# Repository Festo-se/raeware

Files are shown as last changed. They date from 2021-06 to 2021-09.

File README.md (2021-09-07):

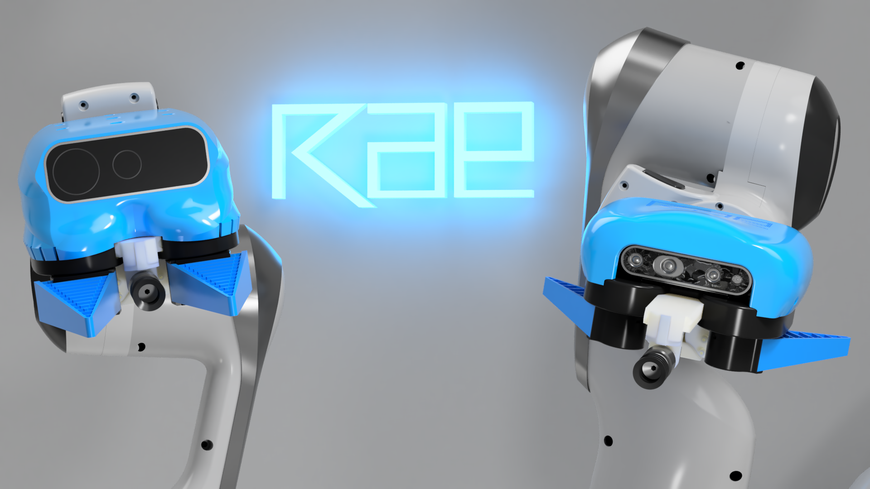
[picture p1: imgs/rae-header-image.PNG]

>[>> Fusion 360 - WebViewer](https://a360.co/2W6mHcp)

## About the Rae Project
Rae stays for *Robot-autonomy-
effector* and is an __OpenSource__ based modular end-of-arm tool with integrated __eye-in-hand__ depth camera which enables researchers, AI-enthusiasts and engineers to develop and deploy autonomous applications for robot manipulators. The 6 different module-types helps to solve various modern challenges in Robotics as for example bin-picking, packaging or tool-based automation. The design originates from the Bachelor-thesis created by Roman Baur in cooporation with Festo SE & Co. KG and the University of applied Sciences in Esslingen.

## [Table of content](#table-of-content)

- [Getting Started](#getting-started)
- [Base-System](#base-system)
- [Realsense System](#realsense-system)
- [Kinect System](#kinect-system)
- [Gripper Fingers](#gripper-fingers)
  - [Festo DAHS-80 Radialgripper](#festo-dahs-80-radialgripper)
  - [Festo DAHS-120 Radialgripper](#festo-dahs-120-radialgripper)
- [Flanges](#flanges)
- [Vacuum Module](#vacuum-module)
  - [double-pump](#double-pump)
  - [big-pump](#big-pump)
- [Suction modules](#suction-modules)
  - [Angular compensation](#angular-compensation)
  - [Linear compensation](#linear-compensation)
- [Electrical Circuit](#electrical-circuit)
- [Cable-set](#cable-set)
- [Credits](#credits)
  - [Bachelors thesis and extension by Roman Baur:](#bachelors-thesis-and-extension-by-roman-baur)
  - [Supervisors Festo SE & Co. KG:](#supervisors-festo-se--co-kg)
  - [Supervisors HS Esslingen:](#supervisors-hs-esslingen)
    - [Bachelors Thesis RAE v 1.0:](#bachelors-thesis-rae-v-10)
    - [RAE v 2.0:](#rae-v-20)

# Getting Started

How I get an working rae:

1. Download the .stl files from the [base-system](base-system) including drive and guide parts
2. Choose whether you want a [realsense](perception-modules/realsense) or a [kinect](perception-modules/kinect) perception system and download the according .stl files.
3. Print it with a high-quality SLS-Printer.
4. Assemble the the printed parts and the electric components with the appropriate screws.
5. Download the Image for the embedded linux called raeos and flash it on an SD-Card. Then boot the system.

> If you want to have an assembled and preinstalled rae, please contact [themakeservice](#)

How to set up my rae:
1. Install the raeros-client on your host system and setup an ethernet or wireless based connection to the rae-system.

# Base-System
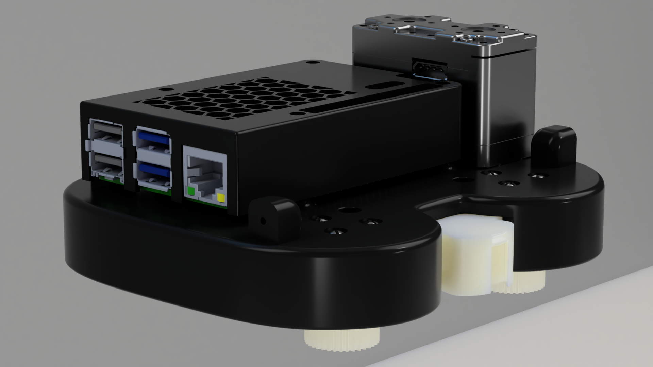
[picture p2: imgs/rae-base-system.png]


> [>> base-system](base-system)

# Realsense System

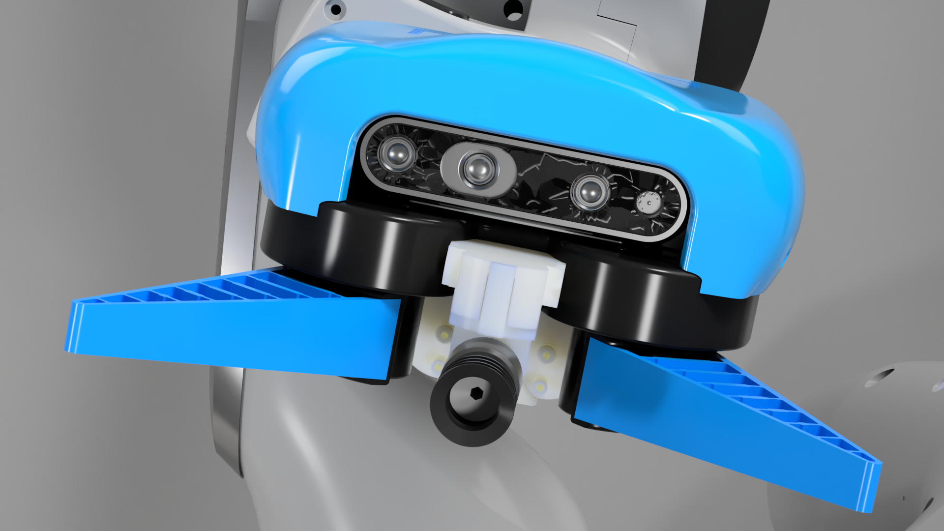
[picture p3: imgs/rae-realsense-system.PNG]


> [>> realsense-system](perception-modules/realsense)

# Kinect System
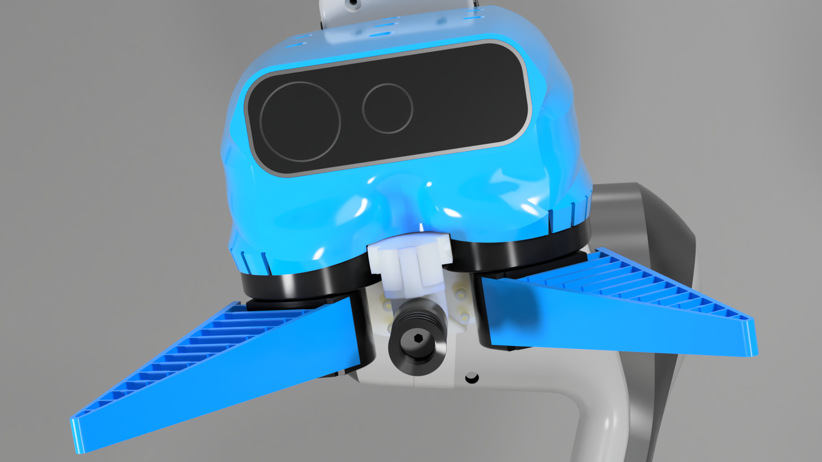
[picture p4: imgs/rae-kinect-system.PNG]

> [>> kinect-system](perception-modules/kinect)

# Gripper Fingers
## Festo DAHS-80 Radialgripper
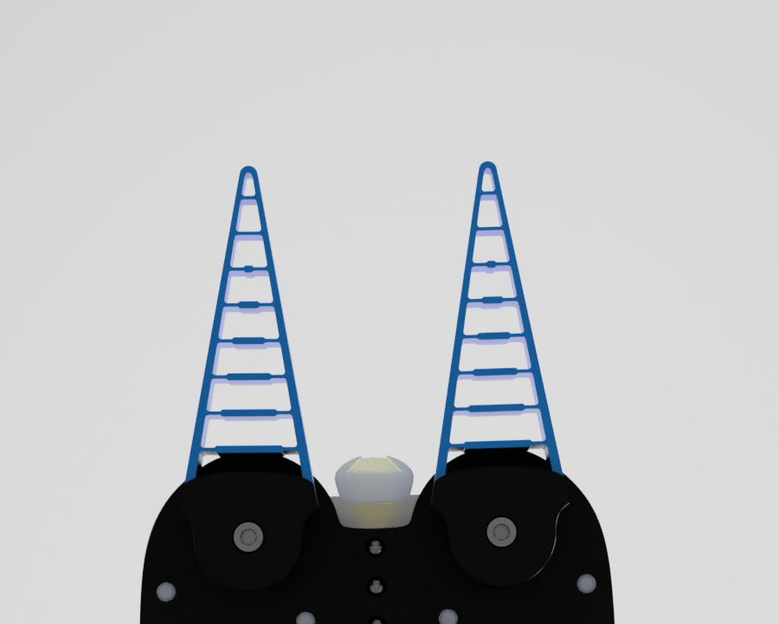
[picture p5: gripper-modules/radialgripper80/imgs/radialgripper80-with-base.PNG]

> [>> radialgripper80](gripper-modules/radialgripper80)
> 
## Festo DAHS-120 Radialgripper
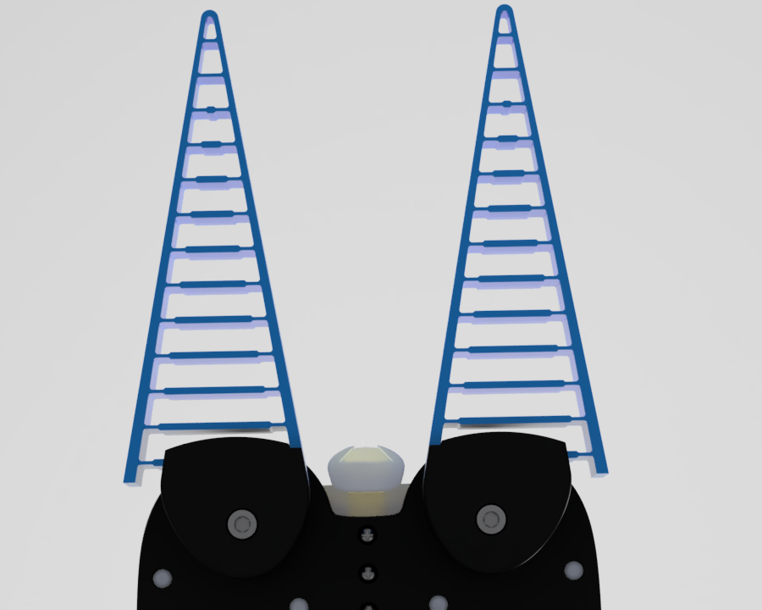
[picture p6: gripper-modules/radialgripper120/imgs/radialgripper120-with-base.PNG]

> [>> radialgripper120](gripper-modules/radialgripper120)
# Flanges
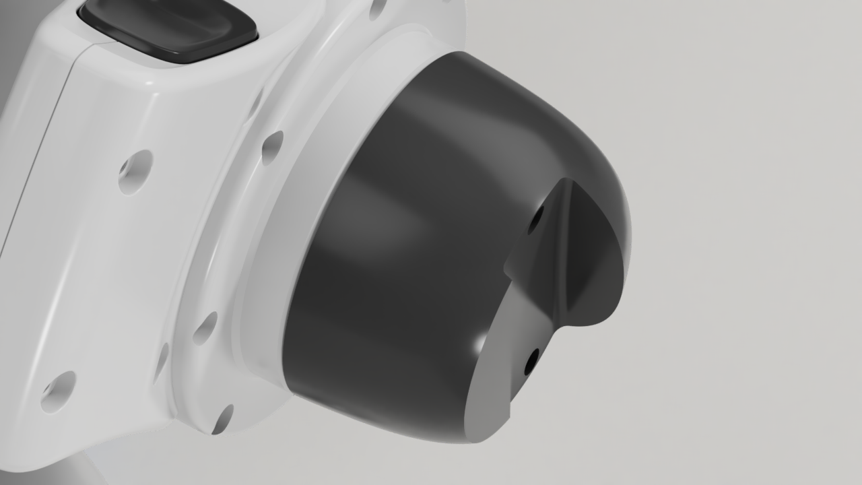
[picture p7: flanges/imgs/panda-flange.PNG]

> [>> Franka-Panda-Flange](flanges)

# Vacuum Module
## double-pump
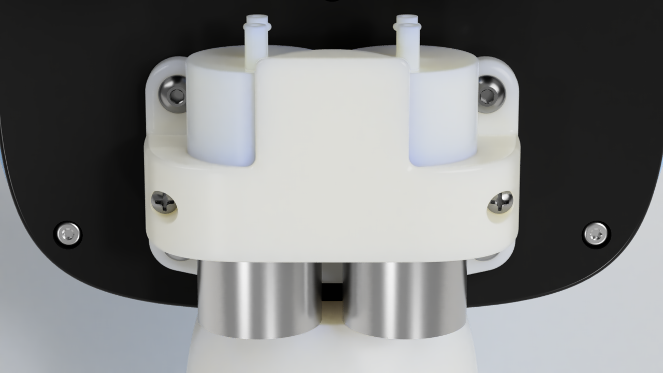
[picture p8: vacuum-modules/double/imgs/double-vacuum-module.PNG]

> [>> double-vacuum-module](vacuum-modules/double)

## big-pump
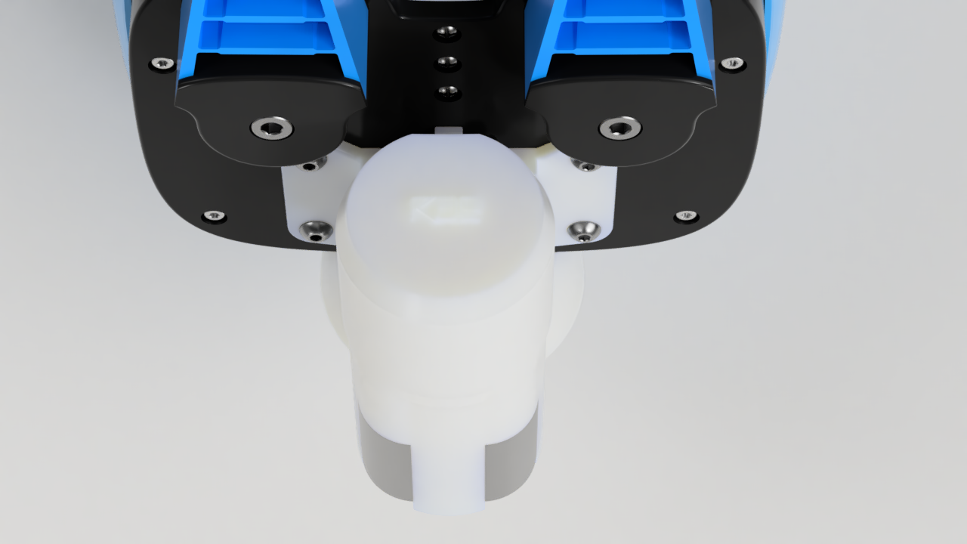
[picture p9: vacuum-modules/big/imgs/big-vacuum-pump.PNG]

> [>> big-vacuum-module](vacuum-modules/big)

# Suction modules
## Angular compensation
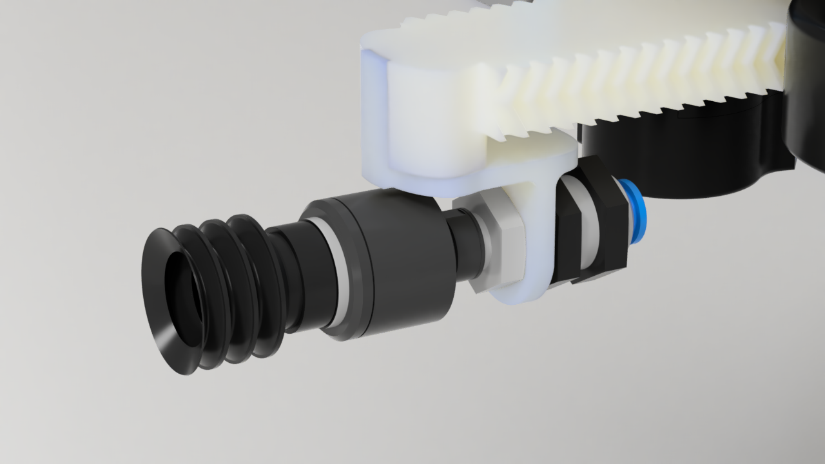
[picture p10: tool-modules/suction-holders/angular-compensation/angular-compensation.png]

> [>> angular-compensation-module](tool-modules/suction-holders/angular-compensation)
> 
## Linear compensation
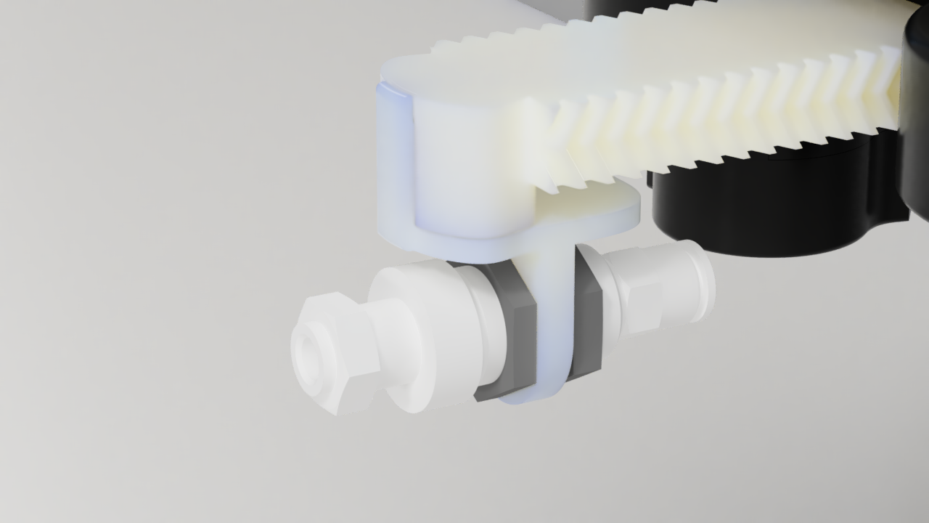
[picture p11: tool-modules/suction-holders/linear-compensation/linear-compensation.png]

> [>> linear-compensation-module](tool-modules/suction-holders/linear-compensation)

# Electrical Circuit
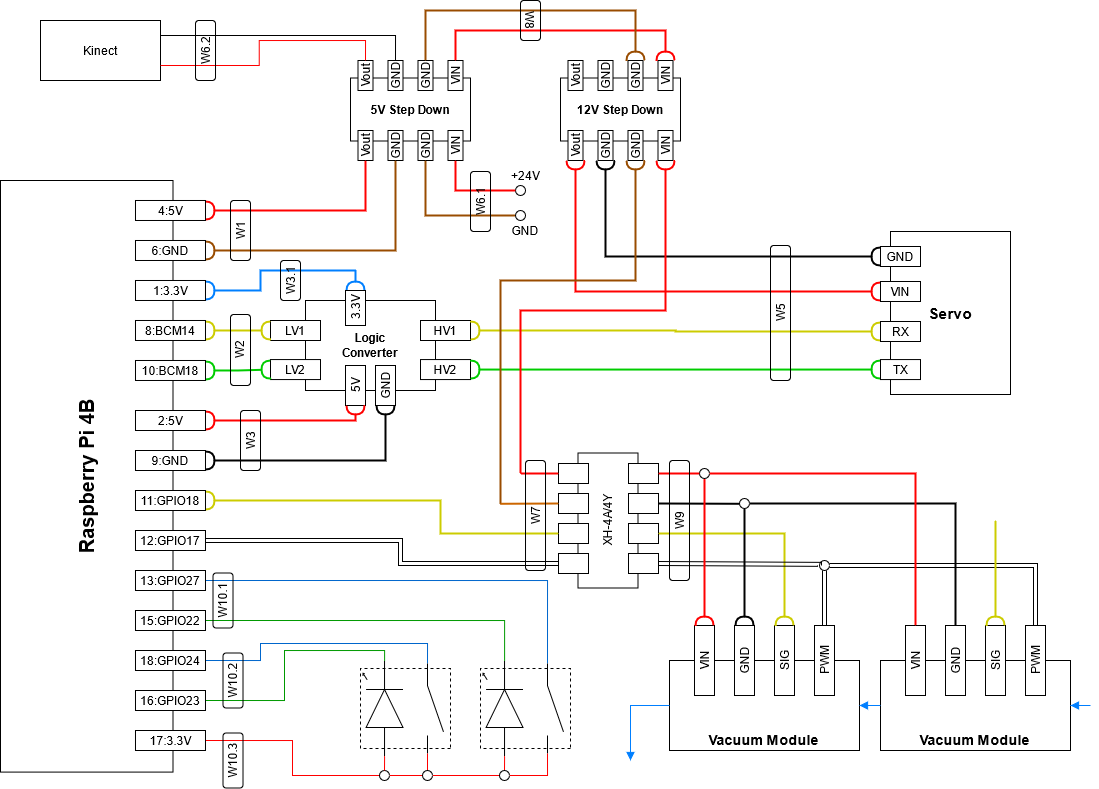
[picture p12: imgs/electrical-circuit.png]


# Cable-set
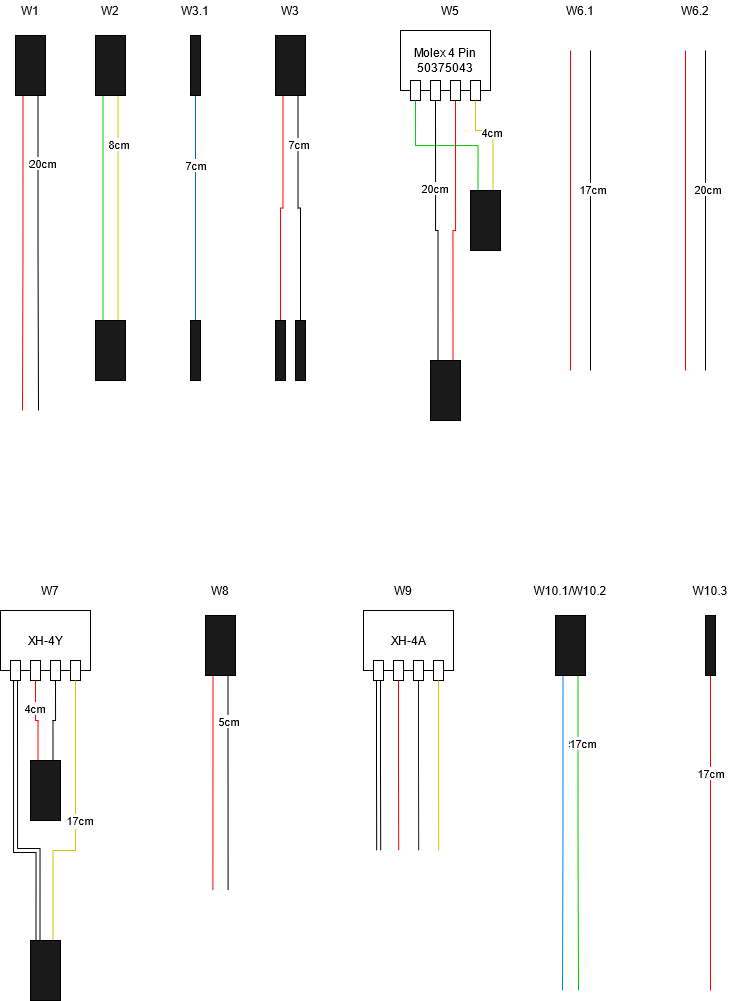
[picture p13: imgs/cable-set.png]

# Credits

## Bachelors thesis and extension by Roman Baur:
* Modular Concept
* Mechanical-, Electrical- and Software-Design

## Supervisors Festo SE & Co. KG:

Daniel Brauchle, Dionysios Satikidis, Timo Schwarzer

## Supervisors HS Esslingen:

### Bachelors Thesis RAE v 1.0:
Prof. Clemens Klöck, Dionysios Satikidis

### RAE v 2.0:
Prof. Thao Dang

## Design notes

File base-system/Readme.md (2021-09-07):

# Dynamixel Base System
>Coming soon
# Lynxmotion Base System
## Assembly animation
Base System assembly (https://www.youtube.com/watch?v=B7FRX5-CgM0 "Base System assembly")

## Partlists
### Electronic
| Name  | Description  | Reference |
|---|---|---|
| Raspberry Pi 4B  | Embedded Linux Computer | [raspberrypi.org](https://www.raspberrypi.org/products/raspberry-pi-4-model-b/)
|Lynxmotion LSS HT1 | Smart Servomotor | [robotshop.com](https://www.robotshop.com/de/de/lynxmotion-smart-servo-lss---hohes-drehmoment-ht1.html)
| Pololu D36V50F12 | Step Down 24V/12V |  [pololu](https://www.pololu.com/product/4095) |
| Pololu D36V50F5 | Step Down 24V/5V | [pololu](https://www.pololu.com/product/4091) |

### Screws
| Name | Application |Qty | Reference |
| --- |--- | --- | --- |
| 3.0X14 TORX rounded head | Case-screws | 6 | [Wuerth](https://eshop.wuerth.de/WUPLAST-Linsenkopfschraube-mit-Innensechsrund-SHR-LIKPF-W1452-T10-109-A3K-3X14/42283%20%2014.sku/de/DE/EUR/) |
| 3.0X6 TORX rounded head | Trapezodial-guide | 3 | [Wuerth](https://eshop.wuerth.de/WUPLAST-Linsenkopfschraube-mit-Innensechsrund-SHR-LIKPF-W1452-T10-109-A3K-3X6/42283%20%206.sku/de/DE/EUR/)|
| 3.0X10 TORX rounded head| Shafts| 6 | [Wuerth](https://eshop.wuerth.de/WUPLAST-Linsenkopfschraube-mit-Innensechsrund-SHR-LIKPF-W1452-T10-109-A3K-3X10/42283%20%2010.sku/de/DE/EUR/) |
| 2-56, 1/4"  SOCKET HEAD | Servomotor | 6 | [McMaster](https://www.mcmaster.com/91251A077/) |
| M5 Square-Nut DIN 557 | Flanges | 2 | [Wuerth](https://eshop.wuerth.de/Produktkategorien/DIN-557-Stahl-5-verzinkt/14013512180106.cyid/1401.cgid/de/DE/EUR/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) |

# Drive Parts
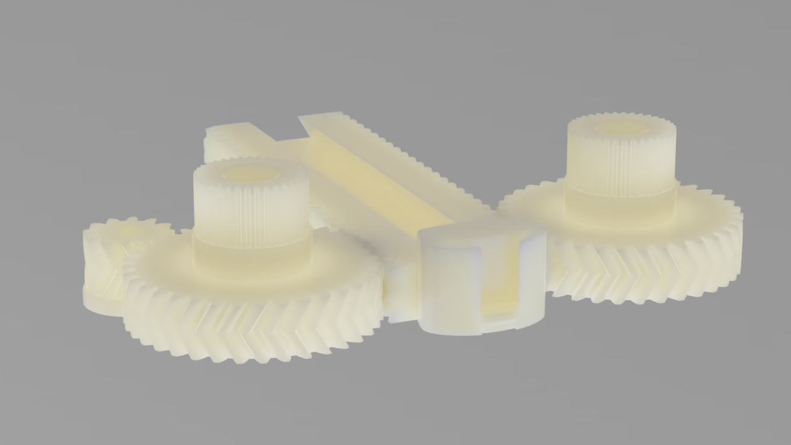
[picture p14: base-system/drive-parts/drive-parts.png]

> [>> drive-parts](drive-parts)

# Metal Guide Parts
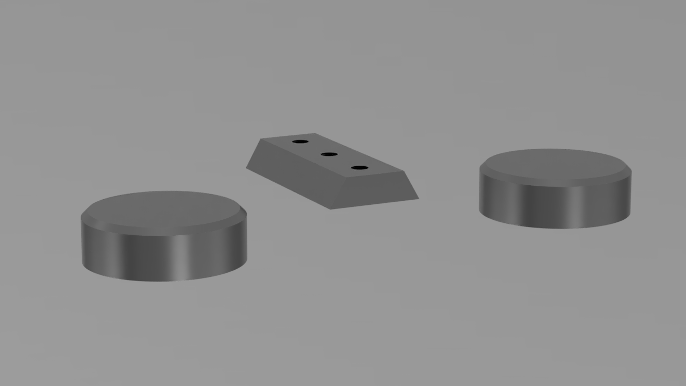
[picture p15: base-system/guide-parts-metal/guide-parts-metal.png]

> [>> metal-guide-parts](guide-parts-metal)

# Nylon Guide Parts
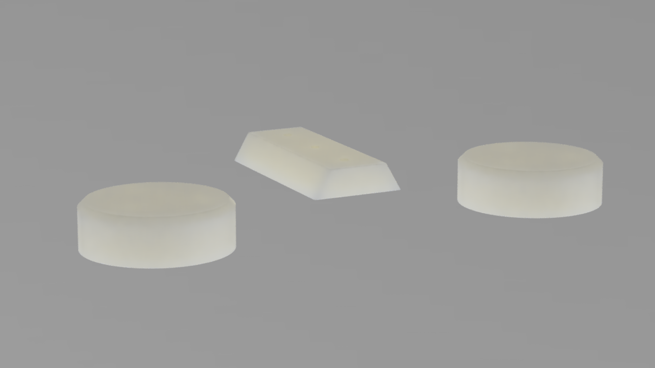
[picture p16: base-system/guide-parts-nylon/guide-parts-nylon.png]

> [>> metal-guide-nylon](guide-parts-nylon)

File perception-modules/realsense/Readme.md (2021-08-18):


Depth Kamera D435i | [specs](https://www.intel.de/content/www/de/de/products/sku/190004/intel-realsense-depth-camera-d435i/specifications.html)

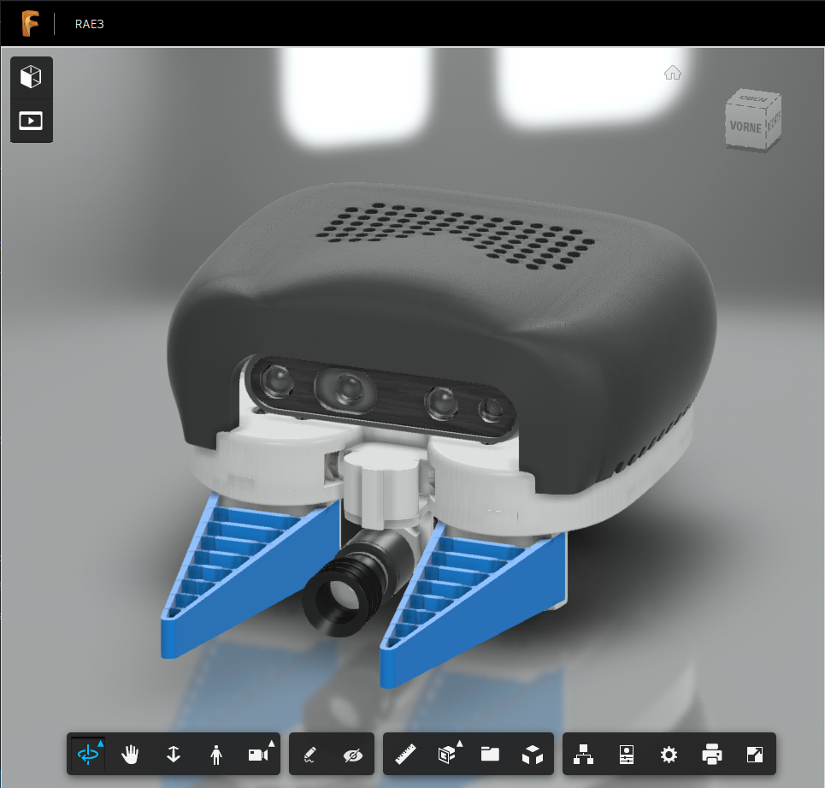
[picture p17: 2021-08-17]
imgs/fusion360-webviewer.PNG

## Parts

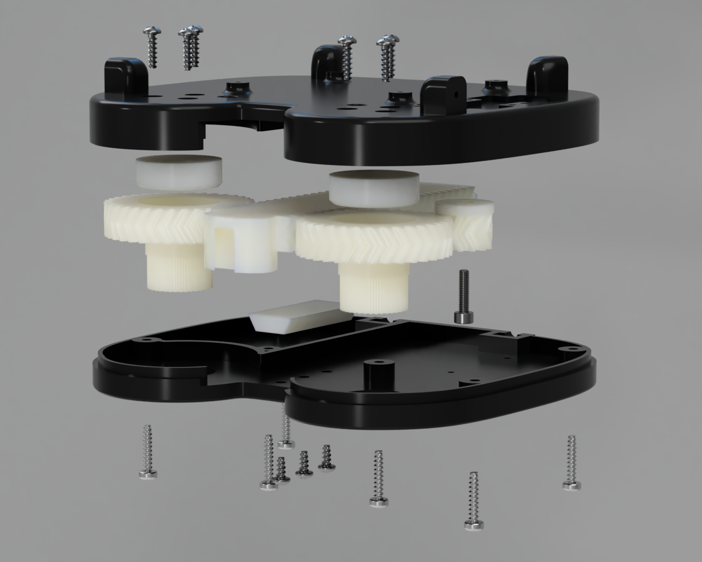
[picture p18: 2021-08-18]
base-system/lynxmotion-system/imgs/exploded-view-mechanical-parts.PNG

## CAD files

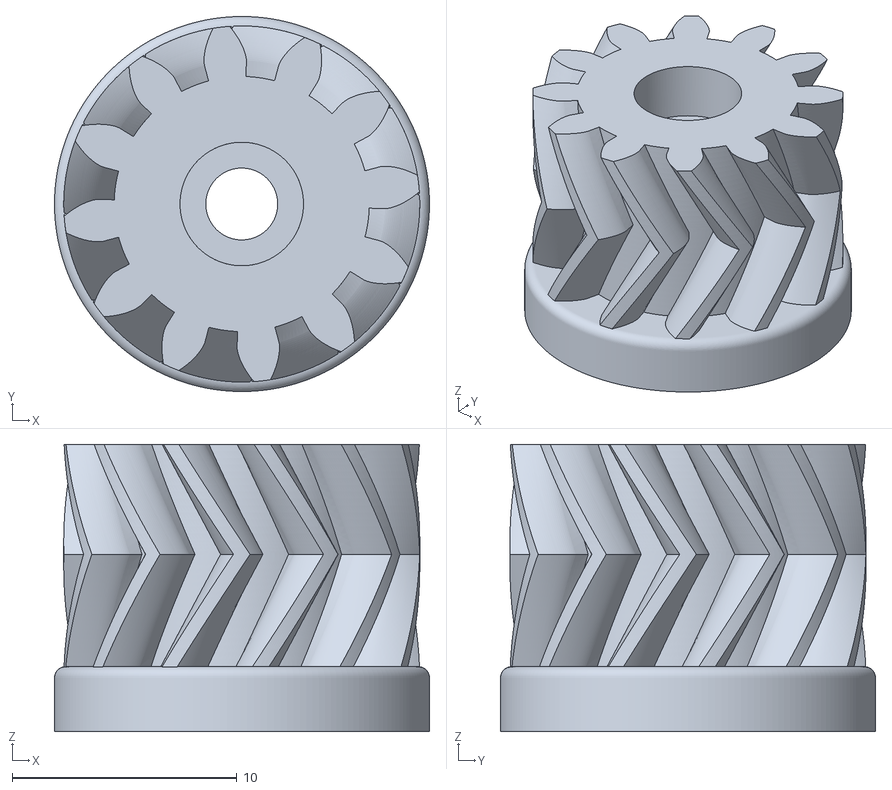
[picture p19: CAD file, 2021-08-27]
base-system/drive-parts/horn.stl
16.7 x 16.7 x 12.8

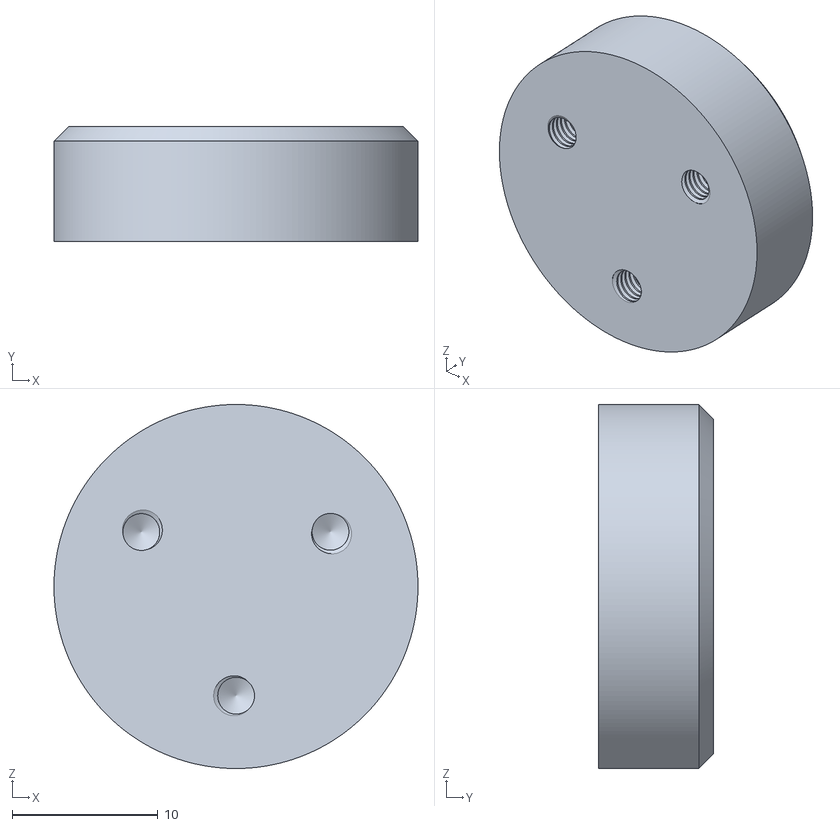
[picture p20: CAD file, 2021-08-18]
base-system/guide-parts-metal/right-shaft.stl
25.0 x 7.90 x 25.0

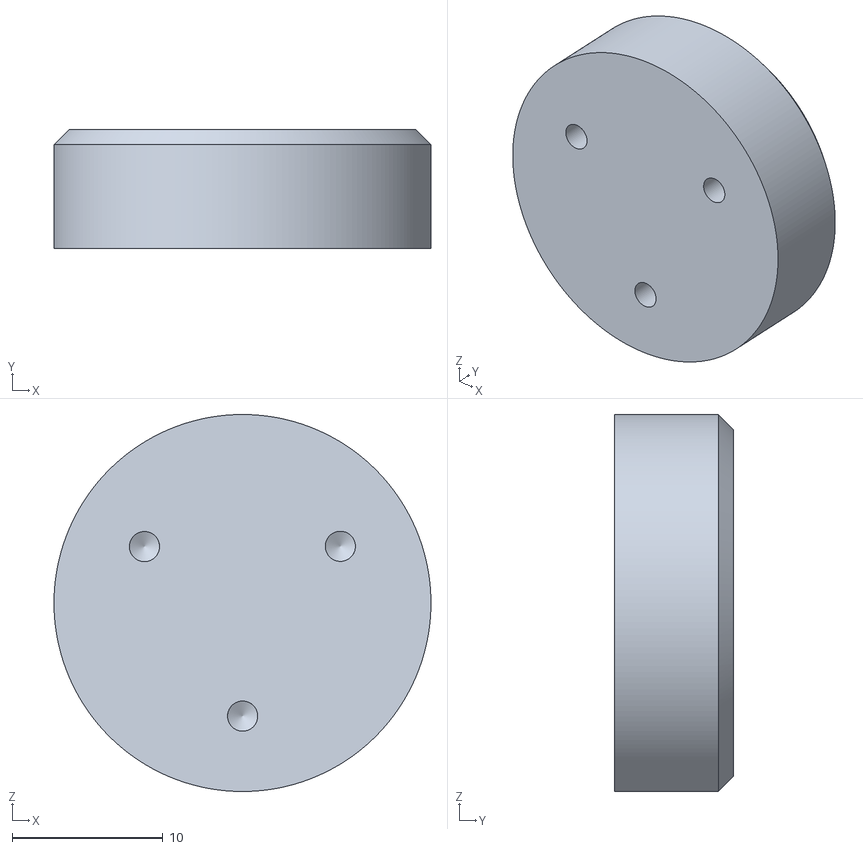
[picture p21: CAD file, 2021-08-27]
base-system/guide-parts-nylon/left-shaft.stl
25.0 x 7.90 x 25.0

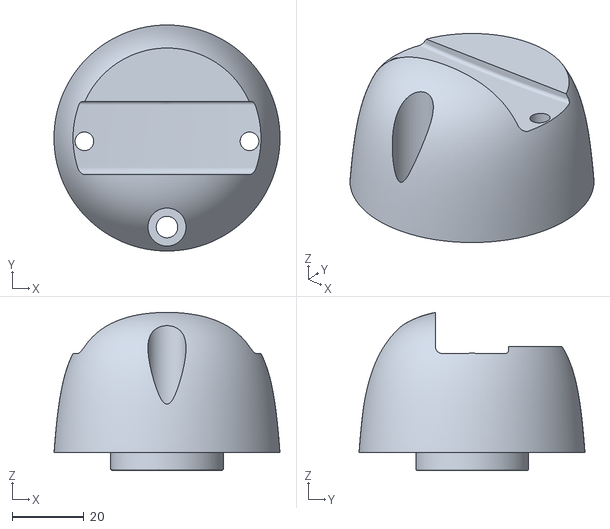
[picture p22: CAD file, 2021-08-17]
flanges/panda-flange.stl
63.0 x 63.0 x 44.1

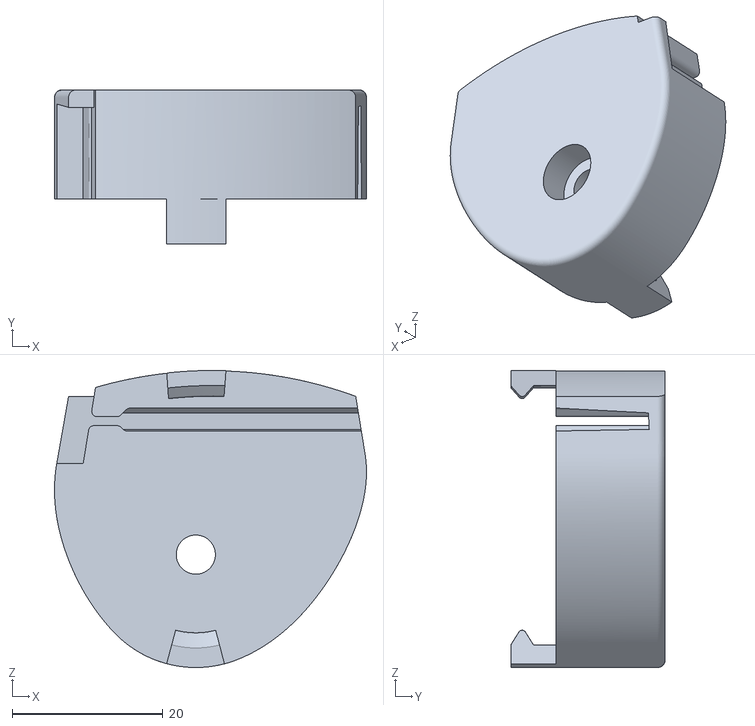
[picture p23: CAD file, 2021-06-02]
gripper-modules/radialgripper120/left_top.stl
41.5 x 20.5 x 39.5

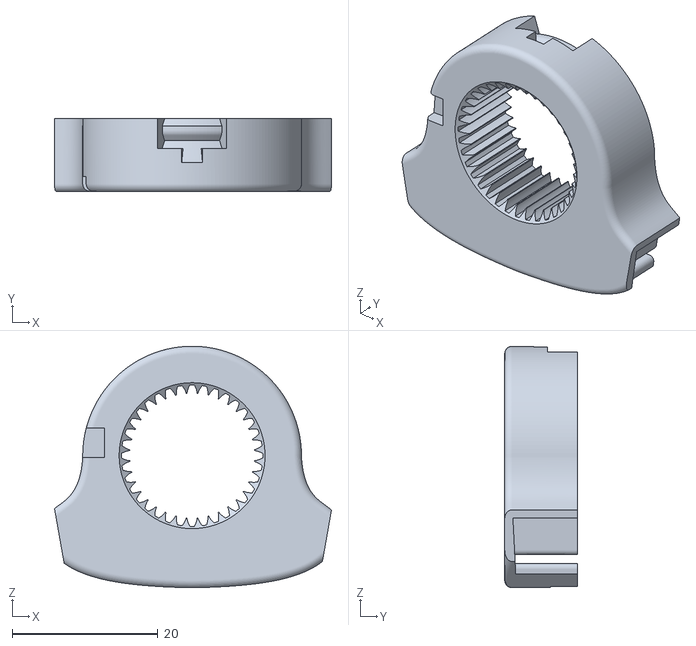
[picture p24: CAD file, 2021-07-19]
gripper-modules/radialgripper80/bottom_left.stl
38.0 x 9.95 x 33.1

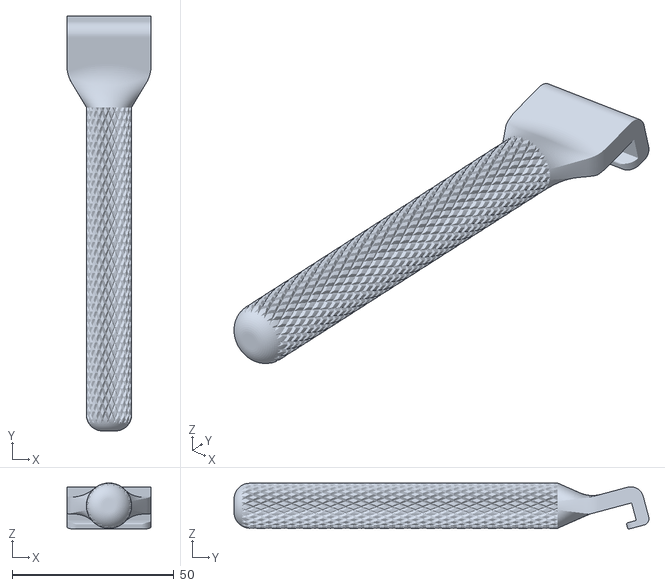
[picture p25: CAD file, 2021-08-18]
perception-modules/realsense/unmount-tool.stl
26.0 x 128.2 x 14.2

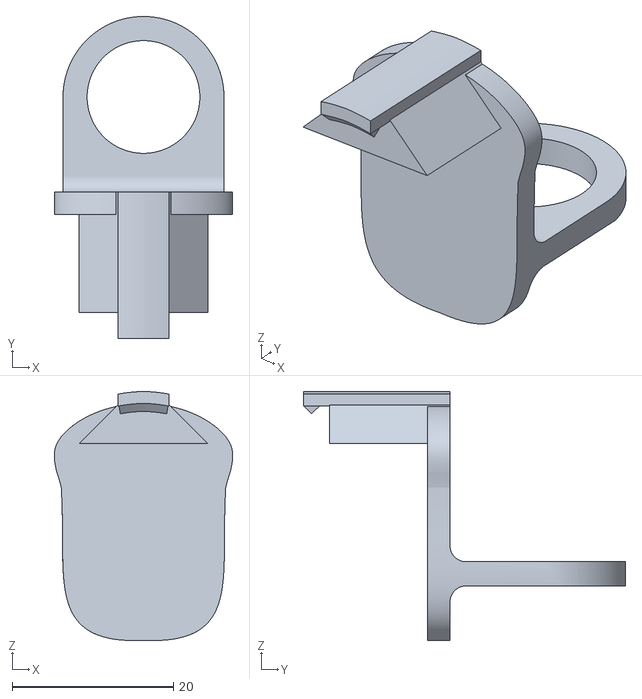
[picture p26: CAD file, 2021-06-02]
tool-modules/suction-holders/angular-compensation/angular_compensation_mount.stl
22.2 x 40.0 x 30.9

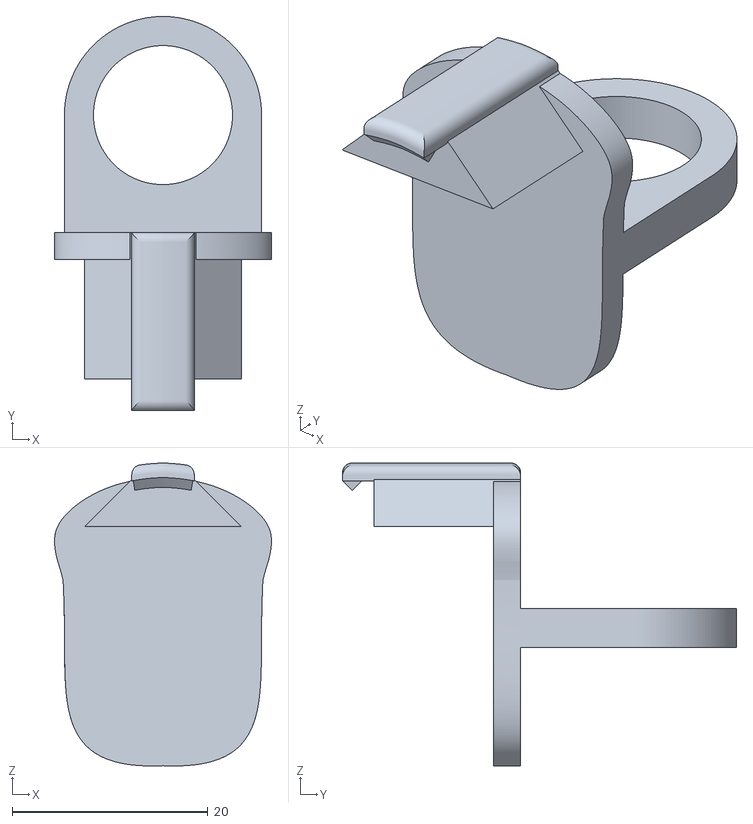
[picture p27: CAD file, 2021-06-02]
tool-modules/suction-holders/linear-compensation/linear-compensation.stl
22.2 x 40.2 x 30.9

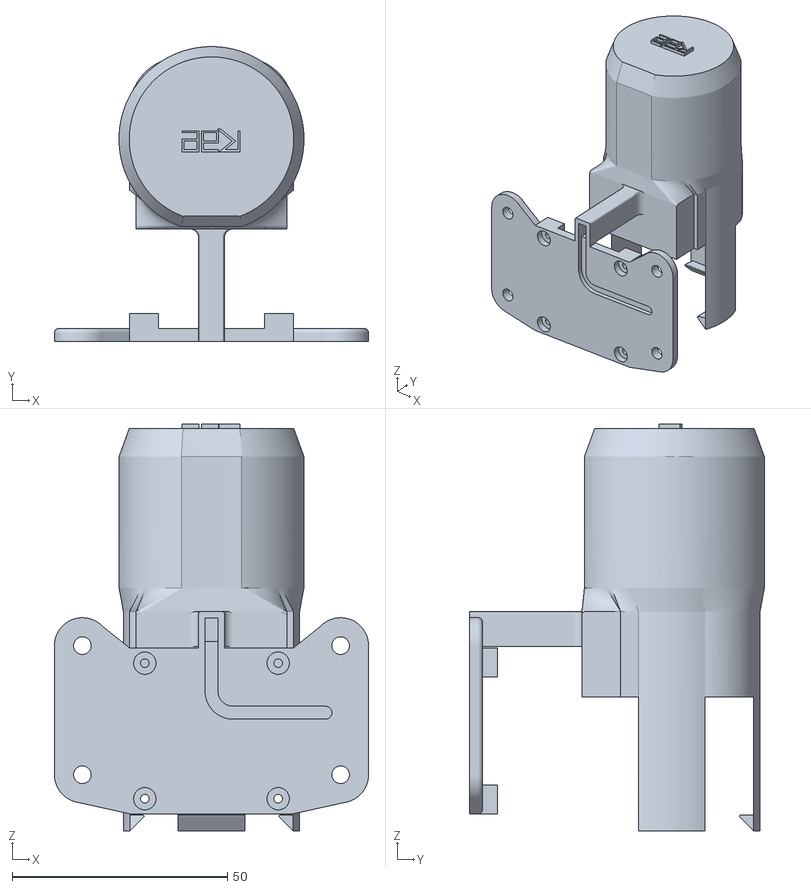
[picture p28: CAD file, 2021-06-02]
vacuum-modules/big/mount.stl
73.0 x 68.5 x 94.6

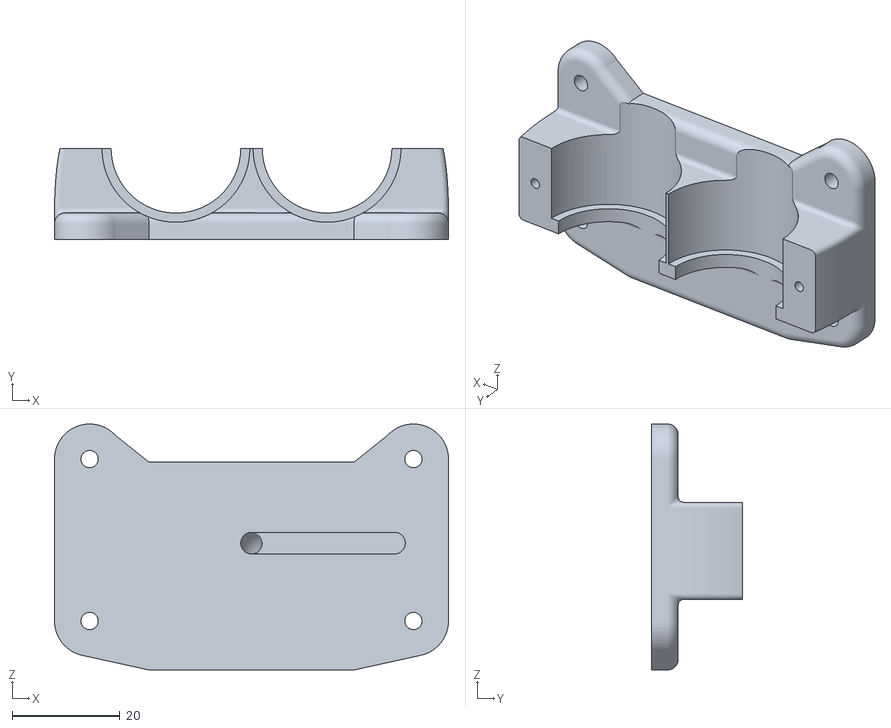
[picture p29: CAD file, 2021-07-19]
vacuum-modules/double/bottom.stl
73.0 x 16.9 x 45.6

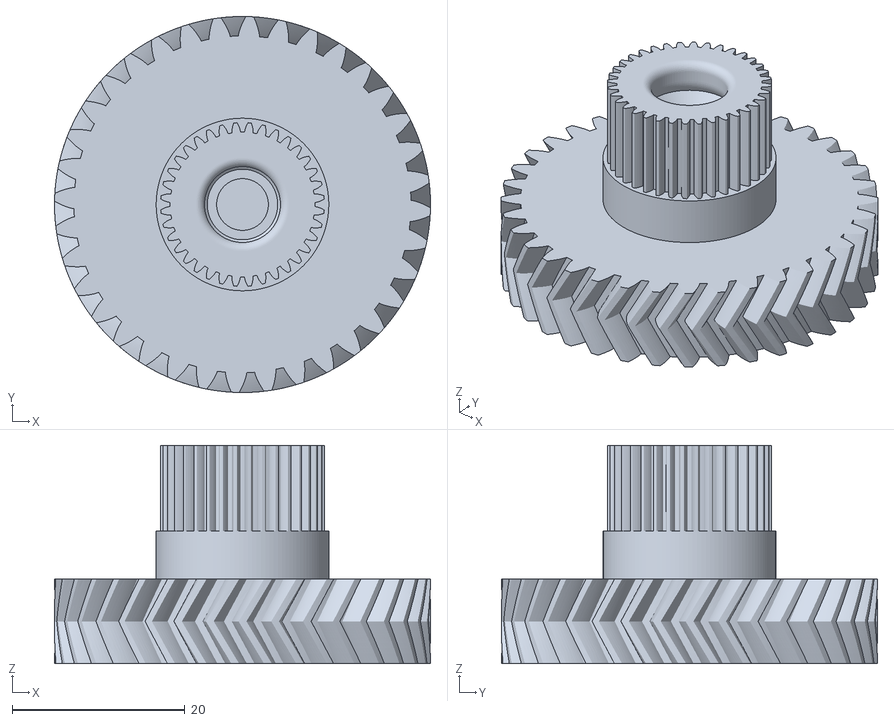
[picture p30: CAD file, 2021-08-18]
base-system/drive-parts/Pinion2.stl
43.6 x 43.6 x 25.3

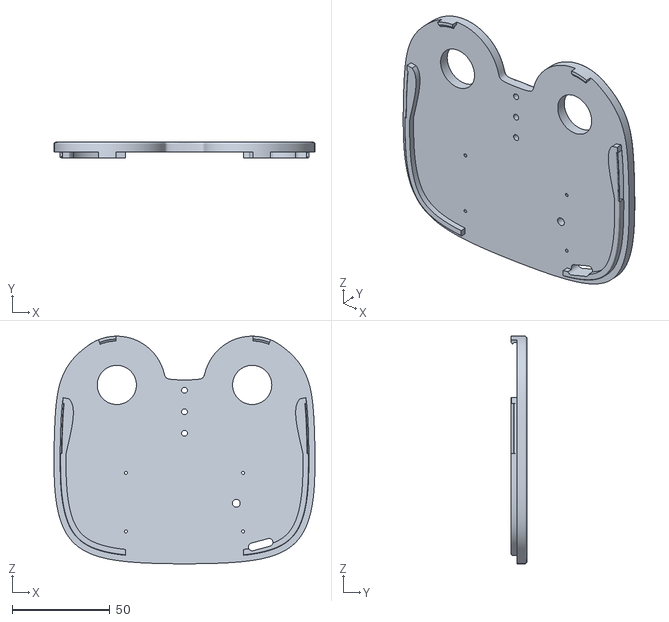
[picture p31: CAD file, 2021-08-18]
base-system/lynxmotion-system/clipsed-case-top.stl
133.6 x 8.00 x 116.5

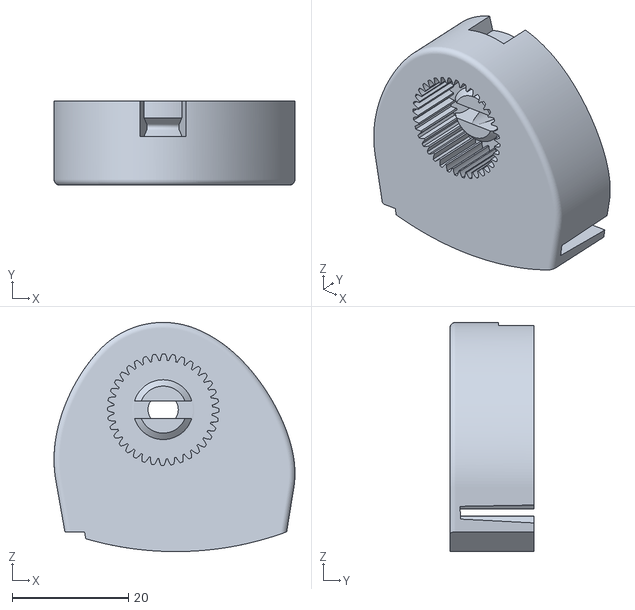
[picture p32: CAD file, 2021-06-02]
gripper-modules/radialgripper120/right_bottom.stl
41.5 x 14.5 x 39.4

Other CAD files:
base-system/guide-parts-metal/left-shaft.stl
base-system/guide-parts-nylon/right-shaft.stl
gripper-modules/radialgripper80/bottom_right.stl
perception-modules/realsense/cam-holder.stl
base-system/drive-parts/Pinion1.stl
base-system/drive-parts/rack.stl
base-system/guide-parts-metal/trapezodial-guide.stl
base-system/guide-parts-nylon/trapezodial-guide.stl
base-system/lynxmotion-system/clipsed-case-bottom.stl
base-system/lynxmotion-system/rpi-case.stl
base-system/lynxmotion-system/screwed-case-bottom.stl
base-system/lynxmotion-system/screwed-case-top.stl
gripper-modules/radialgripper120/left_bottom.stl
gripper-modules/radialgripper120/right_top.stl
gripper-modules/radialgripper80/top_left.stl
gripper-modules/radialgripper80/top_right.stl
vacuum-modules/double/top.stl

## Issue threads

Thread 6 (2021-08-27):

Base-System

romzn, 2021-08-27:
# Acceptance Criteria
- [x] Explosion view screwed case
- [x] Assembly animation
- [x] Full Partlist (screws,electronic)
- [x] Circuit Diagram with draw.io
- [x] Cable Set description
- [x] Image: Gear parts
- [x] Image: Guide parts
- [x] Drawings metal guid parts

Closed 2021-09-07.

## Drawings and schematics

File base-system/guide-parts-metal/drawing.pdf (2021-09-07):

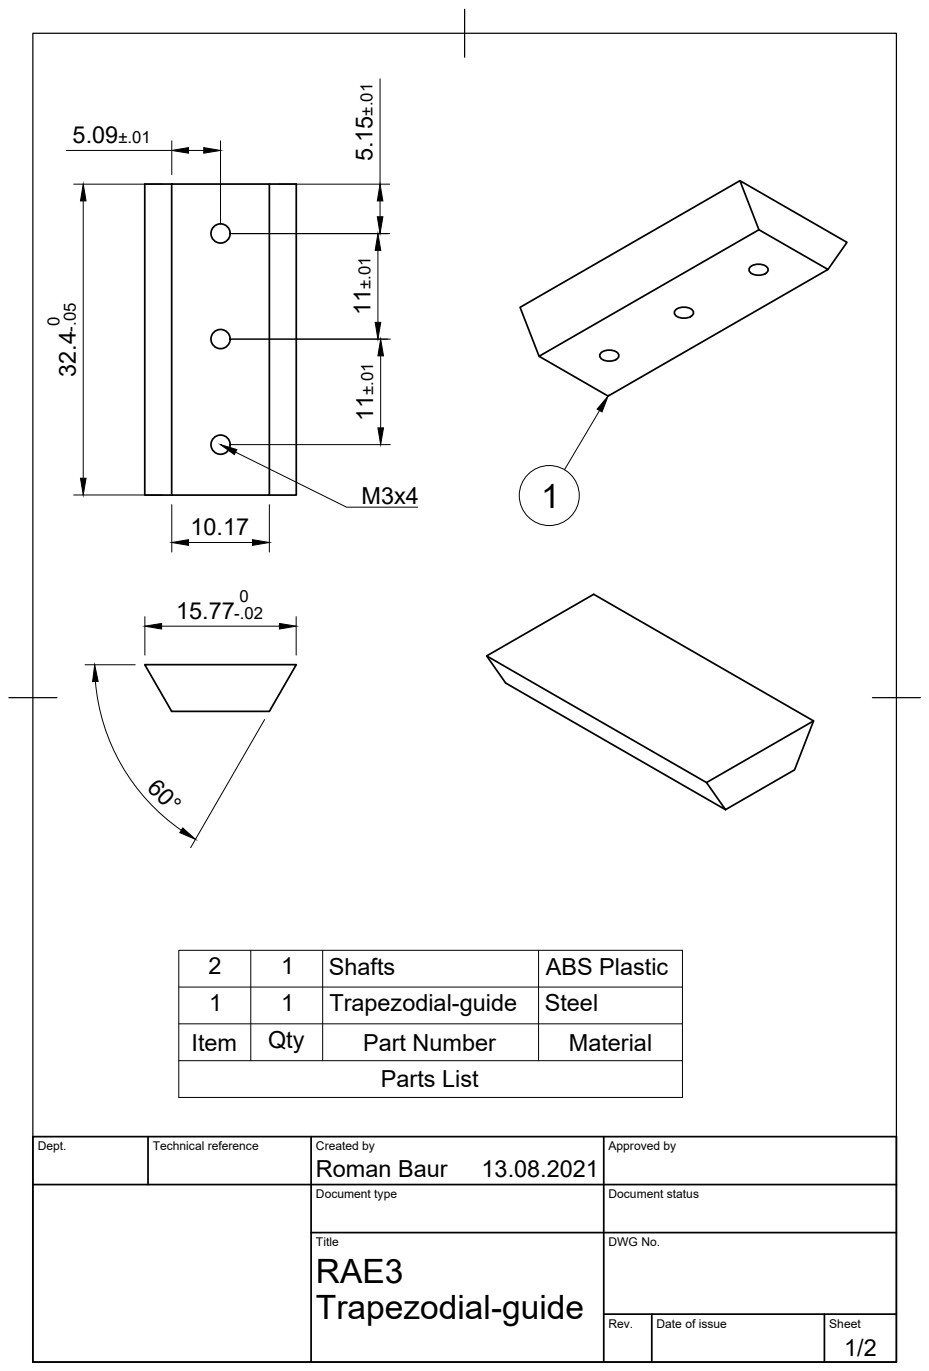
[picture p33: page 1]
Parts List

2 | 1 | Shafts | ABS Plastic
1 | 1 | Trapezodial-guide | Steel
Item | Qty | Part Number | Material

Dept. | Technical reference | Created by Roman Baur 13.08.2021 | Approved by

Document type | Document status

Title RAE3 Trapezodial-guide | DWG No.

Rev. | Date of issue | Sheet 1/2

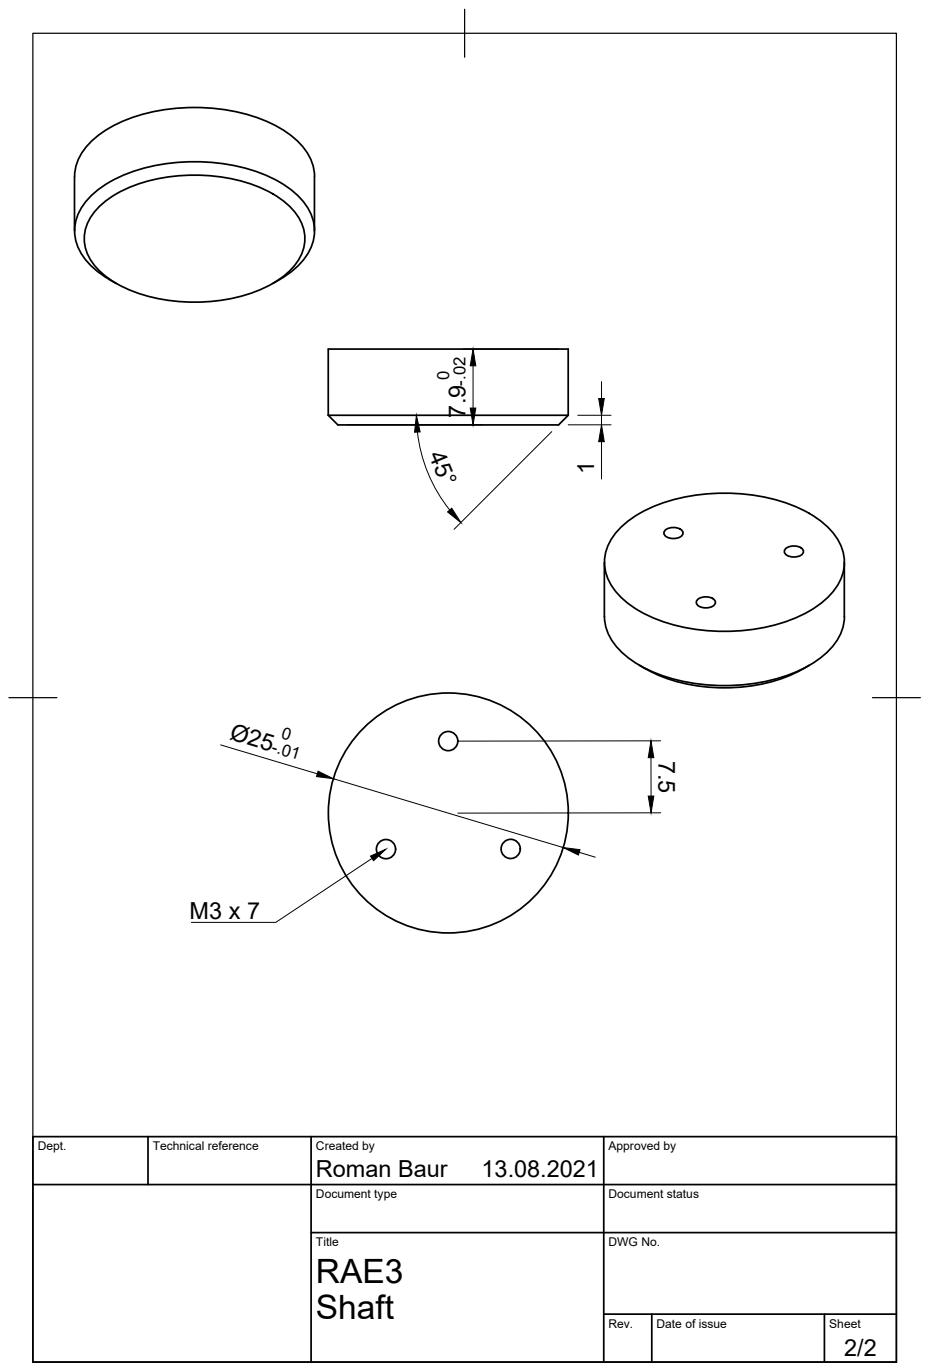
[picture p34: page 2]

Dept. | Technical reference | Created by Roman Baur 13.08.2021 | Approved by

Document type | Document status

Title RAE3 Shaft | DWG No.

Rev. | Date of issue | Sheet 2/2

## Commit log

2021-05-17 First release of Rae .stl files
    [Horn2.stl, Pinion1.stl, Pinion2.stl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]
2021-05-17 Revert "First release of Rae .stl files"
    This reverts commit 43fa2498d06b2b5c9bea2833779ed49f004c89fd.
    [Horn2.stl, Pinion1.stl, Pinion2.stl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]
2021-05-17 Revert "Revert "First release of Rae .stl files""
    This reverts commit 6212bcce93f08f1c79ef1cf7851922dd2b71b186.
    [Horn2.stl, Pinion1.stl, Pinion2.stl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]
2021-05-17 Added missing parts
    [rack.stl, rs-cam-holder.stl, suction_holder_angular_compensation.stl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]
2021-06-02 Inclusion of kinect case
    [Horn2.stl, Pinion1.stl, Pinion2.stl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]
2021-06-02 Added base frame and selected metal printed parts
    [Pinion1.stl, Pinion2.stl, baseframe.stl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]
2021-06-02 moved to metal parts
    [trapezodial-guide.stl]
2021-07-19 Added optimizations
    [baseframe.stl, bottom.stl, bottom_left.stl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]
2021-07-20 Added flange for the franka panda
    [panda-flange.stl]
2021-08-18 Restrructured repository and added screwed case
    [Pinion1.stl, Pinion2.stl, baseframe.stl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]
2021-08-26 revised project structure
    [Pinion1.stl, Pinion2.stl, baseframe.stl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]
2021-08-26 Increased inner offset to cover varnish
    [horn.stl]
2021-08-27 Revised structure and finished top-level readme
    [angular_compensation_mount.stl, bottom.stl, linear-compensation.stl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]
2021-08-27 Renamed folder for rack,pinion,horn
    [Pinion1.stl, Pinion2.stl, horn.stl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]
2021-08-27 name refactoring
    [cam-holder.stl, rs-cam-holder.stl]
2021-08-27 Unmount tool to release clipsed cover
    [unmount-tool.stl]
2021-08-27 Added clipsed baseframe
    [clipsed-case-bottom.stl, clipsed-case-top.stl]
2021-08-27 Added screwed baseframe
    [screwed-case-bottom.stl, screwed-case-top.stl]
2021-08-27 Added guide parts for metal working
    [left-shaft.stl, right-shaft.stl, trapezodial-guide.stl]
2021-08-27 revised structure
    [baseframe.stl, cover.stl, rpi-case.stl]
2021-08-27 Created assembly animation from base system
2021-08-27 Added assembly animation and screw partlist
2021-09-07 Added electrical circuit
2021-09-07 Added electrical circuit and corresponding cable set
2021-09-07 Added air flow through vacuum-pump pipes
